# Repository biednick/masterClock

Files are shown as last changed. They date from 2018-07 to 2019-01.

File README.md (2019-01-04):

# Master Clock

## Features
This module features tap tempo, 1x, 2x, 3x, 4x, 1/2x, 1/3x, and 1/4x clock multiplication/division, and the ability to dial in the clock rate using a potentiometer. A second mode disables tap tempo and allows rate to be adjusted directly using the potentiometer or allows the module to be used as a standard clock mutiplier/divider..

## Files
### Master_Clock_xx.ino
This is the Arduino code. An ISP header on the board allows the microcontroller to be programmed directly.

### masterClock_xx.brd and .sch
These are the Eagle files for the PCB. To order PCBs, gerbers need to be generated using a CAM job in Eagle. A free version of Eagle is available.

### masterClockParts_xx.md
This is the parts list. A Mouser BOM is available at in this file as well.

### masterClock.ai
This is the panel in Adobe Illustrator format. This can be used to manufacture a panel.

## Updates

### 01.1 03JAN19
The original code had major issues with timing. That code has been replaced with a test version of the code that keeps time correctly but only allows the tempo to be set using the potentiometer. All pin deffinitions were left in place to facilitate adding additonal code to meet the desired funsitonality. In additon, I have discovered the anode on LD1 (the bicolor LED) is not connected to VCC. This can be fixed with a jumper wire and will be corrected in the next board revition. 

### 01 24JUN18
First push to GitHub. Currently this design is untested.

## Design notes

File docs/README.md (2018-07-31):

## [Overview](#overview) | [Design](#design) | [Buy](#buy)

# Overview

This module packs a bunch of clock utilities into one small package. The large arcade button makes it easy to set the tempo with the tap of your finger. An external clock input allows the module to function as a traditional clock multiplier and divider. The rate knob has two modes. In mode 1, it modifies the base clock rate allowing you to speed up or slow down the tempo of an external clock or tap tempo. In mode 2 the knob sets the clock rate directly.

# Design

Controlled by an ATMega 328 (the same chip used by the Arduino Uno) this module can easily be reporogrammed using an ISP Programmer and the Arduino IDE. One large button and one knob control all the settings, allowing you to easily dial in the tempo and switch between modes. As a purely digital module the current draw is very low, and the built in 5v regulator eliminates the need for a 5v rail on your power supply.

# Buy

I'll be updating this part soon with a link to buy PCBs on Reverb. For the time being you can email me to purchase development PCBs at a discount. These will be fully functional but have minor issues.

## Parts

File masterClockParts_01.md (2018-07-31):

# Parts List

Mouser BOM: https://www.mouser.com/ProjectManager/ProjectDetail.aspx?AccessID=d6ebbab981

| Name | Part | Package | Source |
| --- | --- | --- | --- |
| R1-10 | Resistor, 1k | 0805 | Mouser |
| C1,C2 | Capacitor, 22pf | 0805 | Mouser |
| c3,C4 | Capacitor, 10uf | 153CLV-0505 | Mouser |
| LED 1-8 | Led | 5mm | Mouser |
| LD1 | Bicolor LED, common anode | 5mm | Amazon |
| IC2 | 7805 voltage regulator | TO252 | Mouser |
| IC3 | ATMega-328 | TQFP32 | Mouser |
| Q1 | Crystal, 16mhz | HC49UP | Mouser |
| SV1 | Pin header, ISP | 2x3 | Mouser |
| SV2 | Pin header, power | 2X5 | Mouser |
| U$1 | Potentiometer, B10k | Alpha 9mm | Mouser |
| U$2-9 | Mono jack switched | Thonkiconn | Modular Addict |
| X1 | Arcade Button (wire) | 30mm | Amazon |

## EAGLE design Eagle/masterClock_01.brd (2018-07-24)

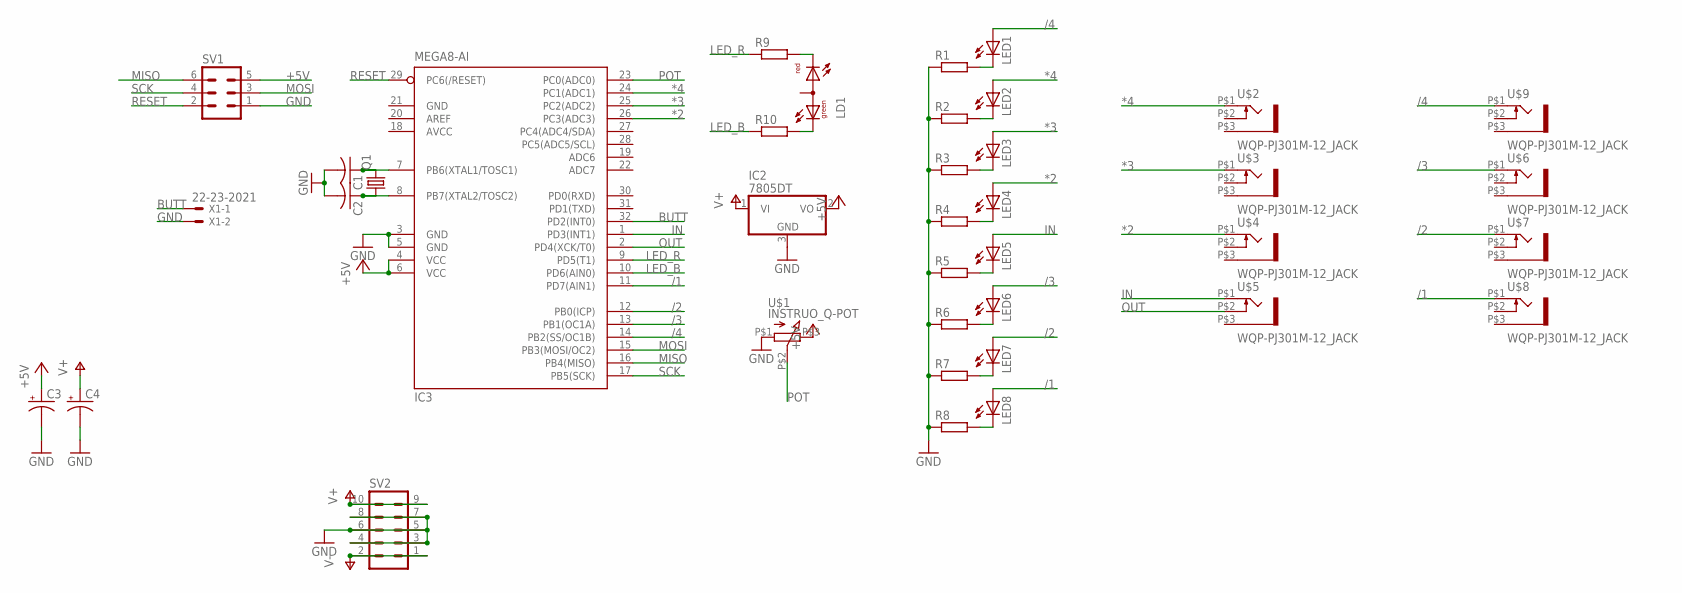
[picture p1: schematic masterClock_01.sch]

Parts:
C1, C2: C-USC0805; C0805
C3, C4: CPOL-US153CLV-0505; 153CLV-0505
IC2: 7805DT; TO252
IC3: MEGA8-AI; TQFP32-08
LD1: DUOLED-RG-A; DUOLED-A-5MM
LED1, LED2, LED3, LED4, LED5, LED6, LED7, LED8: LED5MM
Q1: CRYSTALHC49UP; HC49UP
R1, R2, R3, R4, R5, R6, R7, R8, R9, R10: R; R0805
SV1: MA03-2
SV2: MA05-2
U$1: INSTRUO_Q-POT
U$2, U$3, U$4, U$5, U$6, U$7, U$8, U$9: WQP-PJ301M-12_JACK
X1: 22-23-2021

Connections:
*2: IC3.26 (PC3(ADC3)), LED4.A, U$4.P$1 (2)
*3: IC3.25 (PC2(ADC2)), LED3.A, U$3.P$1 (2)
*4: IC3.24 (PC1(ADC1)), LED2.A, U$2.P$1 (2)
+5V: C3.+, IC2.2 (VO), IC3.4 (VCC), IC3.6 (VCC), SV1.5, U$1.P$3 (3)
/1: IC3.11 (PD7(AIN1)), LED8.A, U$8.P$1 (2)
/2: IC3.12 (PB0(ICP)), LED7.A, U$7.P$1 (2)
/3: IC3.13 (PB1(OC1A)), LED6.A, U$6.P$1 (2)
/4: IC3.14 (PB2(SS/OC1B)), LED1.A, U$9.P$1 (2)
AVCC: IC3.18 (AVCC)
BUTT: IC3.32 (PD2(INT0)), X1.1
GND: C1.2, C2.2, C3.-, C4.-, IC2.3 (GND), IC3.3 (GND), IC3.5 (GND), IC3.21 (GND), R1.1, R2.1, R3.1, R4.1, R5.1, R6.1, R7.1, R8.1, SV1.1, SV2.3, SV2.4, SV2.5, SV2.6, SV2.7, SV2.8, U$1.P$1 (1), X1.2
IN: IC3.1 (PD3(INT1)), LED5.A, U$5.P$1 (2)
LED_B: IC3.10 (PD6(AIN0)), R10.1
LED_R: IC3.9 (PD5(T1)), R9.1
MISO: IC3.16 (PB4(MISO)), SV1.6
MOSI: IC3.15 (PB3(MOSI/OC2)), SV1.3
unnamed: LED1.K (C), R1.2
unnamed: LED2.K (C), R2.2
unnamed: LED3.K (C), R3.2
unnamed: LED4.K (C), R4.2
unnamed: LED5.K (C), R5.2
unnamed: LED6.K (C), R6.2
unnamed: LED7.K (C), R7.2
unnamed: LED8.K (C), R8.2
unnamed: LD1.CR, R9.2
unnamed: LD1.CX (CG), R10.2
unnamed: C1.1, IC3.7 (PB6(XTAL1/TOSC1)), Q1.2
unnamed: C2.1, IC3.8 (PB7(XTAL2/TOSC2)), Q1.1
OUT: IC3.2 (PD4(XCK/T0)), U$5.P$2 (3)
POT: IC3.23 (PC0(ADC0)), U$1.P$2 (2)
RESET: IC3.29 (PC6(/RESET)), SV1.2
SCK: IC3.17 (PB5(SCK)), SV1.4
V+: C4.+, IC2.1 (VI), SV2.9, SV2.10
V-: SV2.1, SV2.2

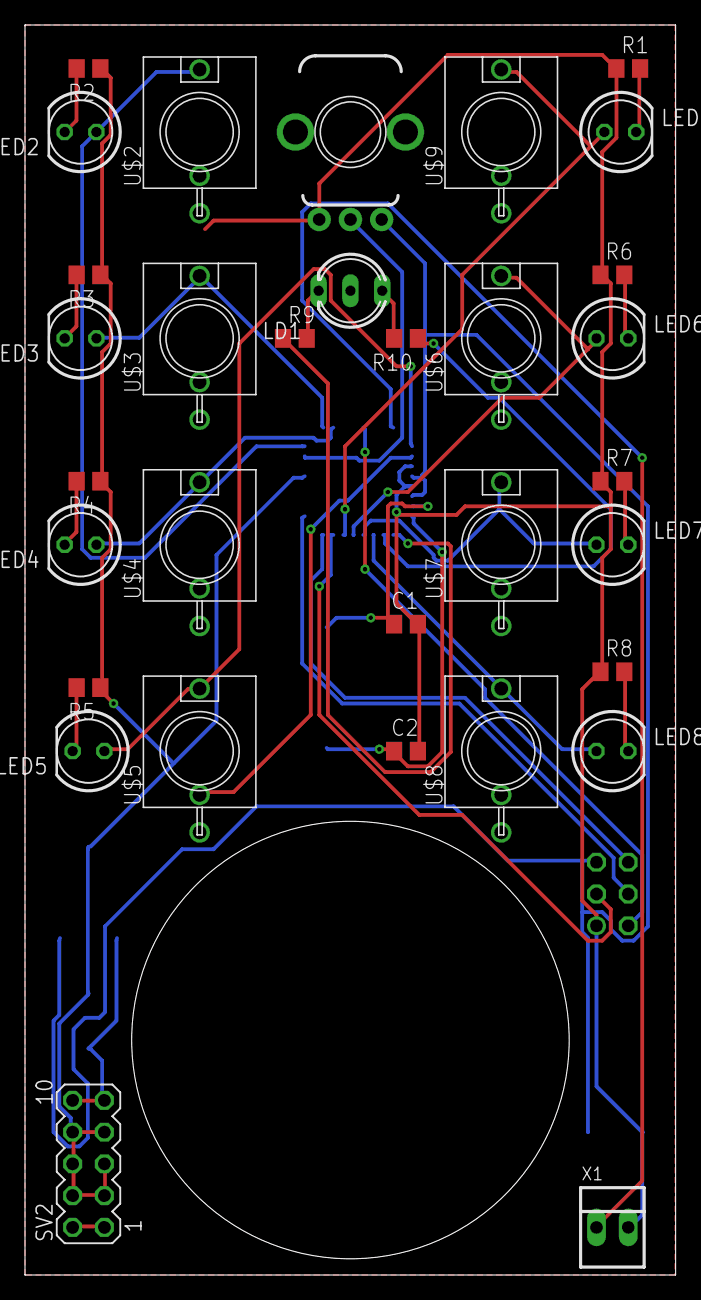
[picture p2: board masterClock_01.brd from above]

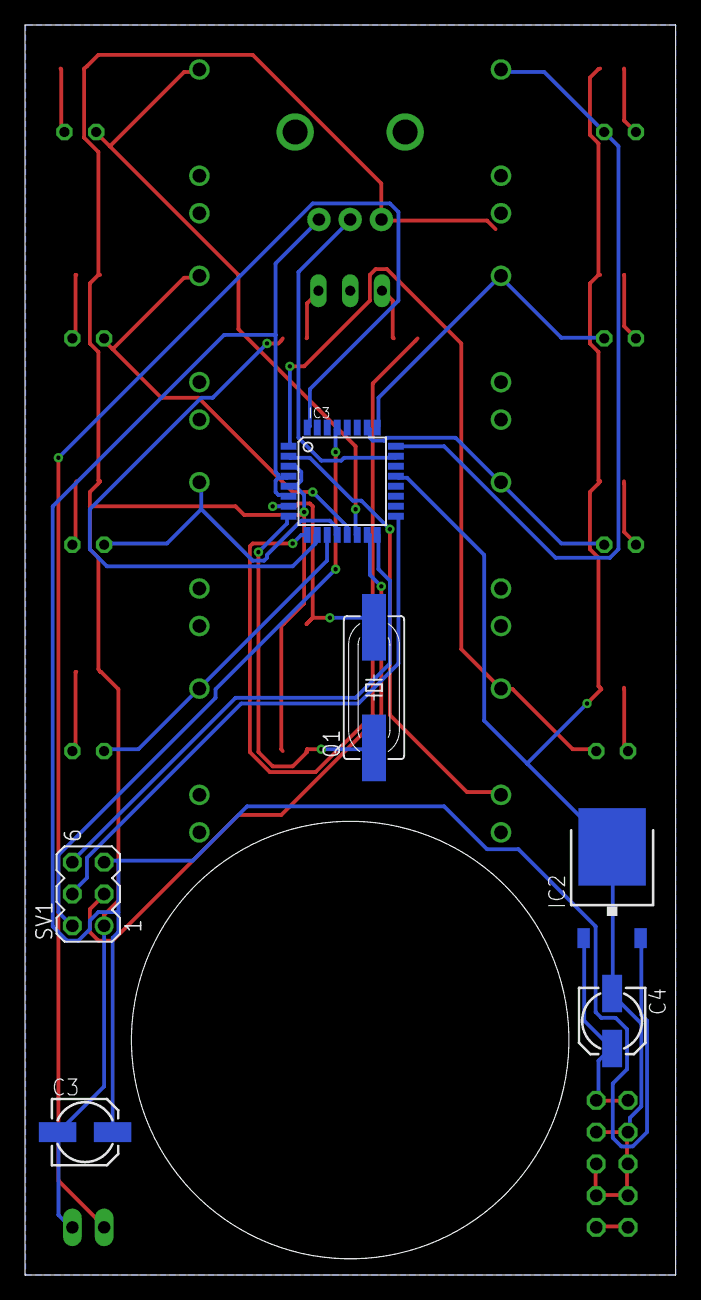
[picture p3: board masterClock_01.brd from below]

Board: 2 copper layers, 52.0 x 100.0 mm, 38 parts (6 on the bottom side), 33 nets.

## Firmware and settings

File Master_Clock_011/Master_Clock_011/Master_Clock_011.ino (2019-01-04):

 #define DIV1 7       //Set up pins for various output
#define DIV2 8
#define DIV3 9
#define DIV4 10
#define MULT2 A3
#define MULT3 A2
#define MULT4 A1
#define OUT 4

#define POT A0      //Potentiometer pin

#define RED 5       //Pins for RB LED; ised to show offet value and mode
#define BLUE 6

#define INTER 3     //Interupt pin, used for external clock

#define BUTTON 2    //Pin for tap tempo button

#define DEBOUNCE 50 //Delays for debouncing and changing mode
#define MODEDELAY 250

int clockTime;
bool mode = 1;

  bool flag = true;
  int time1, time2;
unsigned long D1 = 0, D2 = 0, D3 = 0, D4 = 0, M2 = 0, M3 = 0, M4 = 0, counter = 0, lastClock = 0;
bool D1F = 0, D2F = 0, D3F = 0, D4F = 0, M2F = 0, M3F = 0, M4F = 0;
void setup() {
  pinMode(DIV1, OUTPUT);   //Pinmode for each divition
  pinMode(DIV2, OUTPUT);
  pinMode(DIV3, OUTPUT);
  pinMode(DIV4, OUTPUT);
  pinMode(MULT2, OUTPUT);
  pinMode(MULT3, OUTPUT);
  pinMode(MULT4, OUTPUT);
  pinMode(OUT, OUTPUT);    //Output clock pin, used internally.

  pinMode(BUTTON, INPUT_PULLUP);  //Button pin, pulled hgh to prevent floating
  pinMode(INTER, INPUT_PULLUP);   //Interrupt pin, pulled hogh to avoid floating

}

void loop() {
  if (mode){
  clockTime = 1024 - (analogRead(POT)) + 16;
  }
  else{
    clockTime = tapTempo();
  }
  if (millis() - lastClock > (clockTime / 4)) {
    counter++;
    lastClock = millis();
  }
  if (millis() - D4 > (clockTime / 4)) {
    if (counter % 1 == 0) {
      if (D4F) {
        digitalWrite(DIV4, LOW);
        D4 = millis();
        D4F = !D4F;
      }
      else {
        digitalWrite(DIV4, HIGH);
        D4 = millis();
        D4F = !D4F;
      }
    }
    if (counter % 3 == 0) {
      if (D3F) {
        digitalWrite(DIV3, LOW);
        D3 = millis();
        D3F = !D3F;
      }
      else {
        digitalWrite(DIV3, HIGH);
        D3 = millis();
        D3F = !D3F;
      }
    }
    if (counter % 2 == 0) {
      if (D2F) {
        digitalWrite(DIV2, LOW);
        D2 = millis();
        D2F = !D2F;
      }
      else {
        digitalWrite(DIV2, HIGH);
        D2 = millis();
        D2F = !D2F;
      }
    }
    if (counter % 4 == 0) {
      if (D1F) {
        digitalWrite(DIV1, LOW);
        D1 = millis();
        D1F = !D1F;
      }
      else {
        digitalWrite(DIV1, HIGH);
        D1 = millis();
        D1F = !D1F;
      }
    }

    if (counter % 8 == 0) {
      if (M2F) {
        digitalWrite(MULT2, LOW);
        M2 = millis();
        M2F = !M2F;
      }
      else {
        digitalWrite(MULT2, HIGH);
        M2 = millis();
        M2F = !M2F;
      }
    }

    if (counter % 12 == 0) {
      if (M3F) {
        digitalWrite(MULT3, LOW);
        M3 = millis();
        M3F = !M3F;
      }
      else {
        digitalWrite(MULT3, HIGH);
        M3 = millis();
        M3F = !M3F;
      }
    }

    if (counter % 16 == 0) {
      if (M4F) {
        digitalWrite(MULT4, LOW);
        M4 = millis();
        M4F = !M4F;
      }
      else {
        digitalWrite(MULT4, HIGH);
        M4 = millis();
        M4F = !M4F;
      }
    }
  }
}

int tapTempo(){
  if(digitalRead(BUTTON) == LOW && flag){
    time1 = millis();
    flag = !flag;
    delay(20);
  }
  else if(digitalRead(BUTTON) == LOW){
    time2 = millis();
    flag = !flag;
    delay(20);
  }
  return abs(time1-time2);
}

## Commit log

2018-07-24 Update BOM
2018-07-24 Update File Names
    [masterClock_01.brd, masterClock_01.sch]
2018-07-31 Fix mouser BOM, update site
